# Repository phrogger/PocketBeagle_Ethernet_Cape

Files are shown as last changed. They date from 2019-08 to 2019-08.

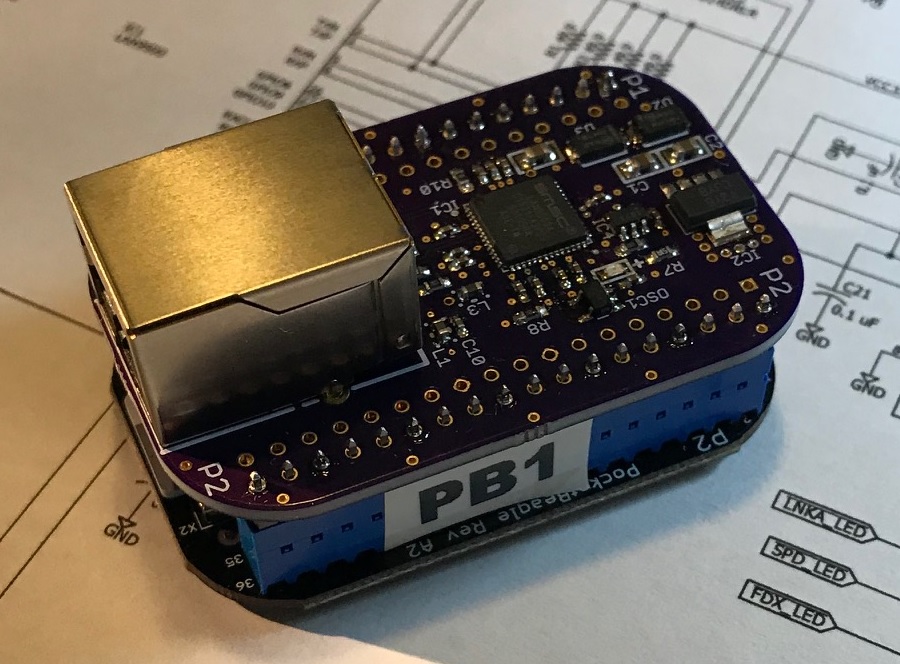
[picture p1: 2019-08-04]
PB_LAN9500A.jpg

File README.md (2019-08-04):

# PocketBeagle_Ethernet_Cape
Design Files for an Ethernet Cape for the PocketBeagle.

This design and documentation are released under the TAPR Open Hardware License.
https://www.tapr.org/ohl.html
There is no warranty as to suitability or applicability for any purpose.
There may be additional licenses or restrictions associated with the use of the Microchip LAN9500A device.

## Notes:
Board Files are Eagle 7.7

The PocketBeagle is configured so that USB Port 0 is a "slave port" only, and is the port pinned out to the Micro-USB connector on the PocketBeagle.

USB Port 1 is configured as a Master, only. It is pinned out to the I/O Expansion Connector P1, pins 3, 5, 7, 9, 11, 13, and 15. This is the port used by this Ethernet 'Cape'.

This design uses a QFN package and surface mount parts as small as 0402, in order to fit the Ethernet interface in a space as small as the PocketBeagle footprint. It is not an appropriate project for someone not experienced in SMT assembly.

The PocketBeagle has a totally symmetrical IO connector configuration. There is nothing that prevents the reversed or offset insertion of this cape. Components may be damaged if the cape is installed backwards, or offset.

This design includes an EEPROM for the permanent assignment of a MAC address to the Ethernet interface. There are software tools for the programming of this EEPROM device in the LAN9500A section of the Microchip website.
Obtaining a legitimate MAC address for use in any assembled boards is the responsibility of the builder.

Bare PC boards built from this Eagle ".brd" file are available from OshPark, minimum order of three boards:
https://oshpark.com/shared_projects/GOEnFXdS

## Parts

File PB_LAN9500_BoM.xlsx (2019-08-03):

PB_LAN9500 BoM
Partlist
Exported from PB_LAN9500.sch at 11/11/2017 3:51 PM
Part | Value | Device | Package | Library | Sheet | Manu | Manu Part No | Supplier | Supplier Part No | Notes
C01 | 1u | C-USC0805 | C0805 | 0G_RCL | 3 | KEMET | C0805C105K4RACTU | Mouser | 80-C0805C105K4R | 16 V X7R
C02 | 1u | C-USC0805 | C0805 | 0G_RCL | 3
C22 | 1u | C-USC0805 | C0805 | 0G_RCL | 2
C03 | 0.1uF | C-USC0402 | C0402 | 0G_RCL | 2 | KEMET | C0402C104K9RACTU | Mouser | 80-C0402C104K9R | 6.3V X7R
C04 | 0.1uF | C-USC0402 | C0402 | 0G_RCL | 2
C05 | 0.1uF | C-USC0402 | C0402 | 0G_RCL | 2
C06 | 0.1uF | C-USC0402 | C0402 | 0G_RCL | 2
C07 | 0.1uF | C-USC0402 | C0402 | 0G_RCL | 2
C08 | 0.1uF | C-USC0402 | C0402 | 0G_RCL | 2
C09 | 0.1uF | C-USC0402 | C0402 | 0G_RCL | 2
C10 | 0.1uF | C-USC0402 | C0402 | 0G_RCL | 2
C11 | 0.1uF | C-USC0402 | C0402 | 0G_RCL | 2
C12 | 0.1uF | C-USC0402 | C0402 | 0G_RCL | 2
C14 | 0.1uF | C-USC0402 | C0402 | 0G_RCL | 2
C15 | 0.1uF | C-USC0402 | C0402 | 0G_RCL | 2
C16 | 0.1uF | C-USC0402 | C0402 | 0G_RCL | 2
C17 | 0.1uF | C-USC0402 | C0402 | 0G_RCL | 2
C18 | 0.1uF | C-USC0402 | C0402 | 0G_RCL | 2
C19 | 0.1uF | C-USC0402 | C0402 | 0G_RCL | 2
C20 | 0.1uF | C-USC0402 | C0402 | 0G_RCL | 2
C21 | 0.1uF | C-USC0402 | C0402 | 0G_RCL | 2
D1 | LEDSMT0603 | LEDSMT0603 | LED0603 | 0G_LED_TVS | 2 | Lite-On
D2 | MBRAF1540 | MBRAF1540 | SMA-FL | 0G_Diode | 3 | ON | MBRAF1540T3G | Mouser | 863-MBRAF1540T3G
D3 | MBRAF1540 | MBRAF1540 | SMA-FL | 0G_Diode | 3 | ON | MBRAF1540T3G | Mouser | 863-MBRAF1540T3G
IC1 | LAN9500 | LAN9500 | QFN56 | 0G_Ethernet | 2 | MicroChip | LAN9500A-ABZJ | Mouser | 886-LAN9500A-ABZJ-TR
IC2 | LP38693 | LP38693 | SOT-223-4 | 0G_Regulators | 3 | TI | LP38693MP-3.3/NOPB | Mouser | 926-38693MP-3.3/NOPB
 |  |  |  |  |  | TI | LP38693MP-3.3/NOPB | Digikey | LP38693MP-3.3/NOPBCT-ND
IC3 | TPD4E0014DRLR | TPD4E0014DRLR | SOT-553-6 | 0G_Ethernet | 2 | TI | TPD4E001DRLR | Mouser | 595-TPD4E001DRLR
IC4 | 93AA66AT-I/OT | 93AA66AT-I/OT | SOT23-6 | 0G_Ethernet | 2 | MicroChip | 93AA66AT-I/OT | Mouser | 579-93AA66AT-I/OT
J1 | J0011D01BNL | J0011D01BNL | J0011D01BNL | 0G_Ethernet | 2 | Pulse | J0011D01BNL | Mouser | 673-J0011D01BNL
L1 | 220 | L0603AS | L0603AS | 0G_Ethernet | 2 | Murata | BLM18KG221SN1D | Mouser | 81-BLM18KG221SN1D | 220 Ohm 2.2A
L2 | 220 | L0603AS | L0603AS | 0G_Ethernet | 2
L3 | 220 | L0603AS | L0603AS | 0G_Ethernet | 2
OSC1 | 25 MHz | SIT2024B | SOT23-5 | 0G_Oscillators | 2 | SiTime | SIT2024BA-S2-33E-25.000000G | Digikey | 1473-1598-1-ND
PB1 | POCKETBEAGLE_OUTLINE | POCKETBEAGLE_OUTLINE | PB_OUTLINE | 0G_PockletBeagle | 3
R01 | 49.9 | R-US_R0603 | R0603 | 0G_Passives | 2 | Yageo | RC0603FR-0749R9L | Digikey | 311-49.9HRCT-ND
R02 | 49.9 | R-US_R0603 | R0603 | 0G_Passives | 2 | Yageo | RC0603FR-0749R9L | Digikey | 311-49.9HRCT-ND
R03 | 49.9 | R-US_R0603 | R0603 | 0G_Passives | 2 | Yageo | RC0603FR-0749R9L | Digikey | 311-49.9HRCT-ND
R04 | 49.9 | R-US_R0603 | R0603 | 0G_Passives | 2 | Yageo | RC0603FR-0749R9L | Digikey | 311-49.9HRCT-ND
R05 | 332 | R-US_R0603 | R0603 | 0G_Passives | 2 | Yageo | RC0603FR-07332RL | Digikey | 311-332HRCT-ND
R06 | 332 | R-US_R0603 | R0603 | 0G_Passives | 2 | Yageo | RC0603FR-07332RL | Digikey | 311-332HRCT-ND
R07 | 332 | R-US_R0603 | R0603 | 0G_Passives | 2 | Yageo | RC0603FR-07332RL | Digikey | 311-332HRCT-ND
R08 | 12.0k | R-US_R0603 | R0603 | 0G_Passives | 2 | Vishay | CRCW060312K0FKEA | Mouser | 71-CRCW0603-12K-E3
R09 | 12.0k | R-US_R0603 | R0603 | 0G_Passives | 2 | Vishay | CRCW060312K0FKEA | Mouser | 71-CRCW0603-12K-E3
R10 | 0 | R-US_R0603 | R0603 | 0G_Passives | 3 | Yageo | RC0603JR-070RL | Mouser | 603-RC0603JR-070RL
R11 | 10k | R-US_R0603 | R0603 | 0G_Passives | 2 |  |  | Mouser |  | Any R0603 10K or substitute 12.0k (R08)

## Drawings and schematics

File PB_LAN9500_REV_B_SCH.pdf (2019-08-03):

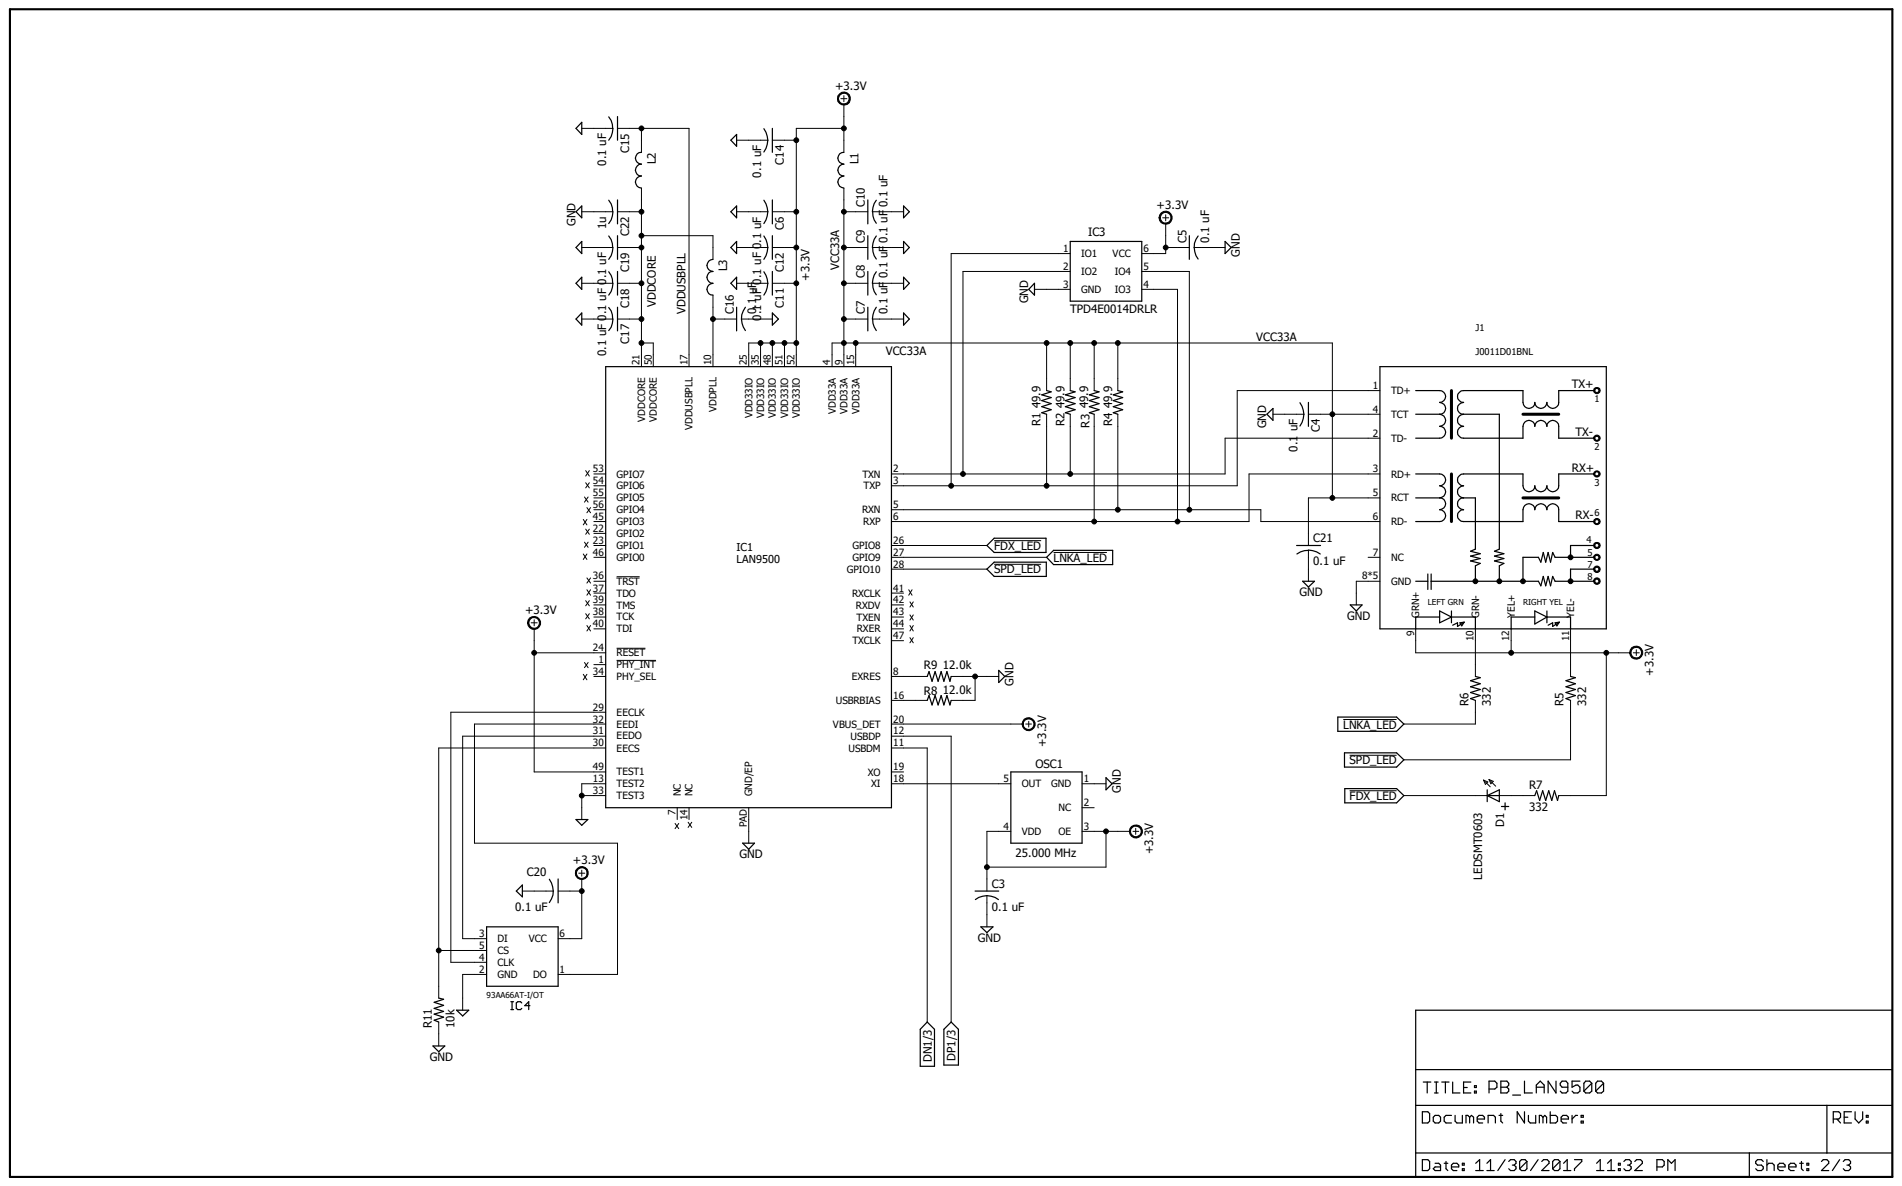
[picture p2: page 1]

9 VDD33A 15 TEST1 49 TEST2 13 VDD33IO 48 PHY_SEL 34 TRST 36 RXCLK 41 RXDV 42 TXEN 43 RXER 44 TXCLK 47

7 GPIO10 28 GPIO9 27 GPIO8 26 GPIO7 53 GPIO6 54 GPIO5 55 GPIO4 56 GPIO3 45 GPIO2 22 GPIO1 23 GPIO0 46 RESET 24 EECLK 29 EEDI 32 EEDO 31 EECS 30 TEST3 33 TDO 37 TMS 39 TCK 38 TDI 40 NC 14 GND/EP PAD

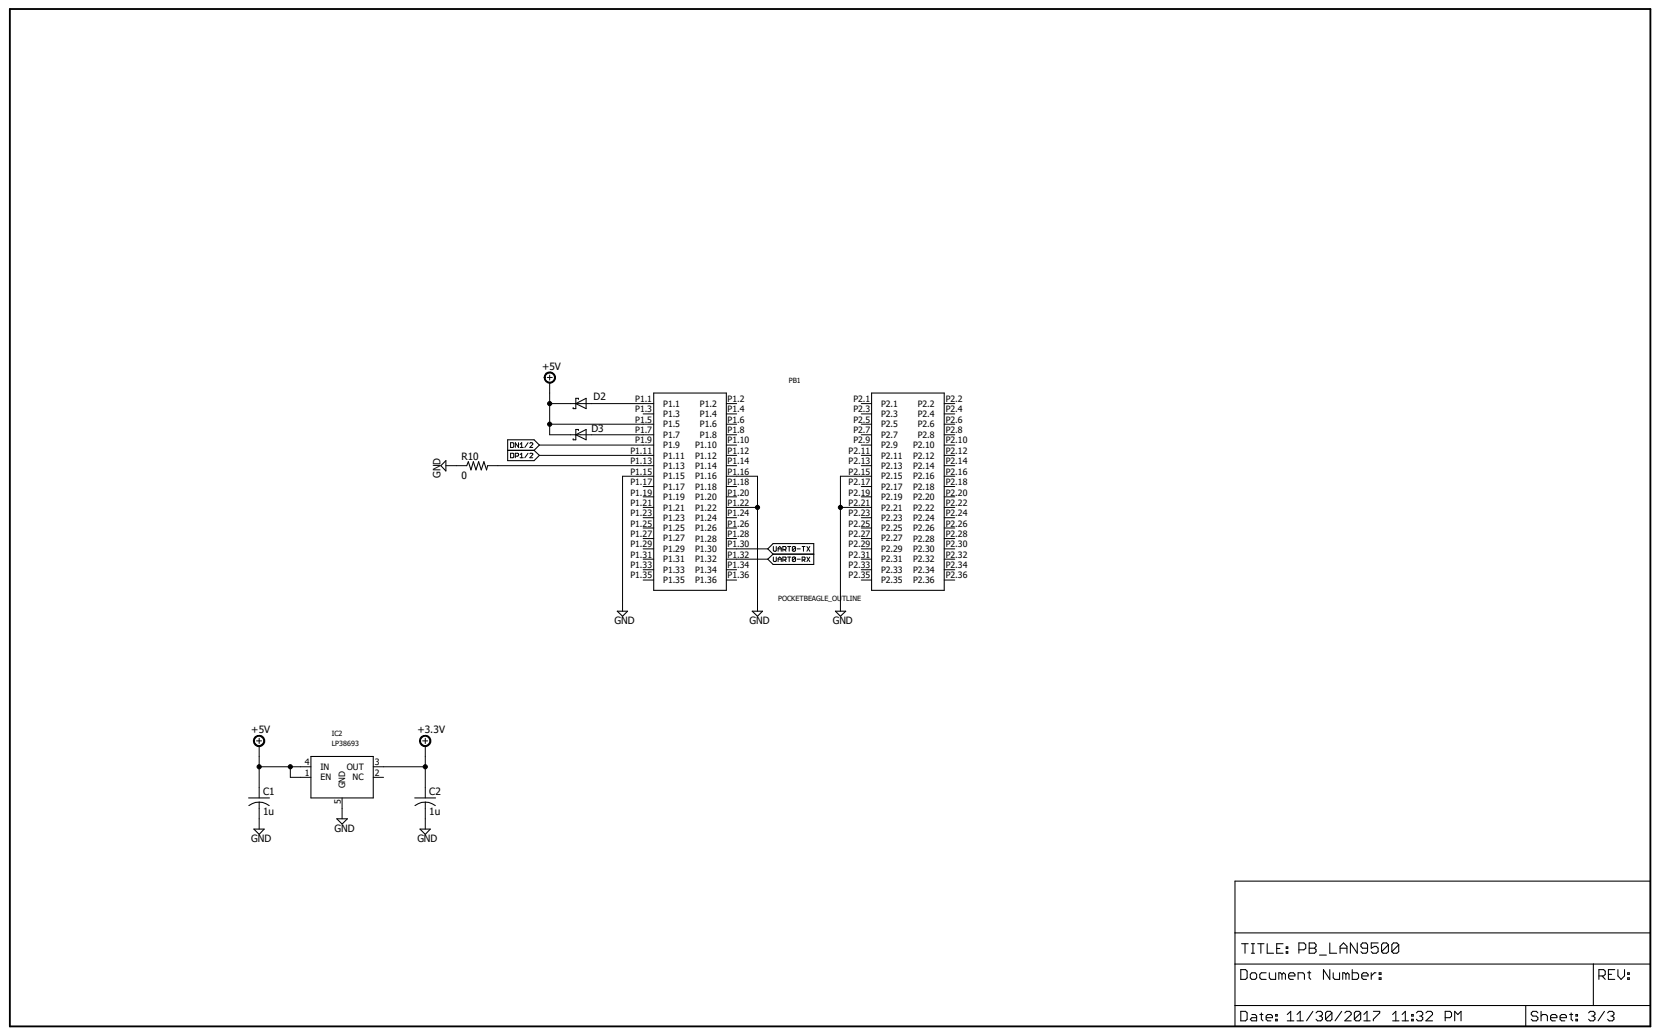
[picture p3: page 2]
POCKETBEAGLE_OUTLINE; 1u GND; GND; GND +5V GND; 5 NC 2 OUT 3 C1 C2

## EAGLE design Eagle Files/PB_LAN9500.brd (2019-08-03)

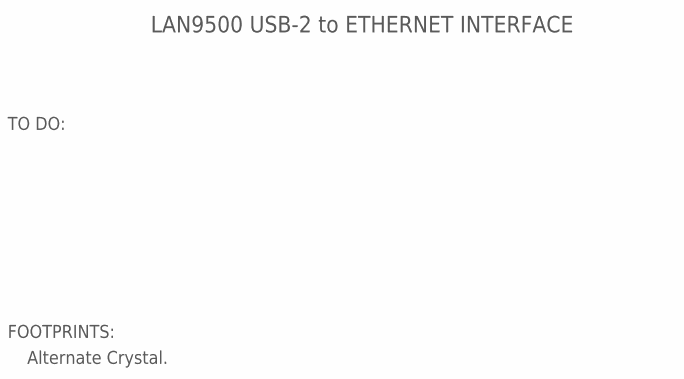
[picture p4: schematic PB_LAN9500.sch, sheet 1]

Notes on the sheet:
LAN9500 USB-2 to ETHERNET INTERFACE
TO DO:
FOOTPRINTS:
Alternate Crystal.

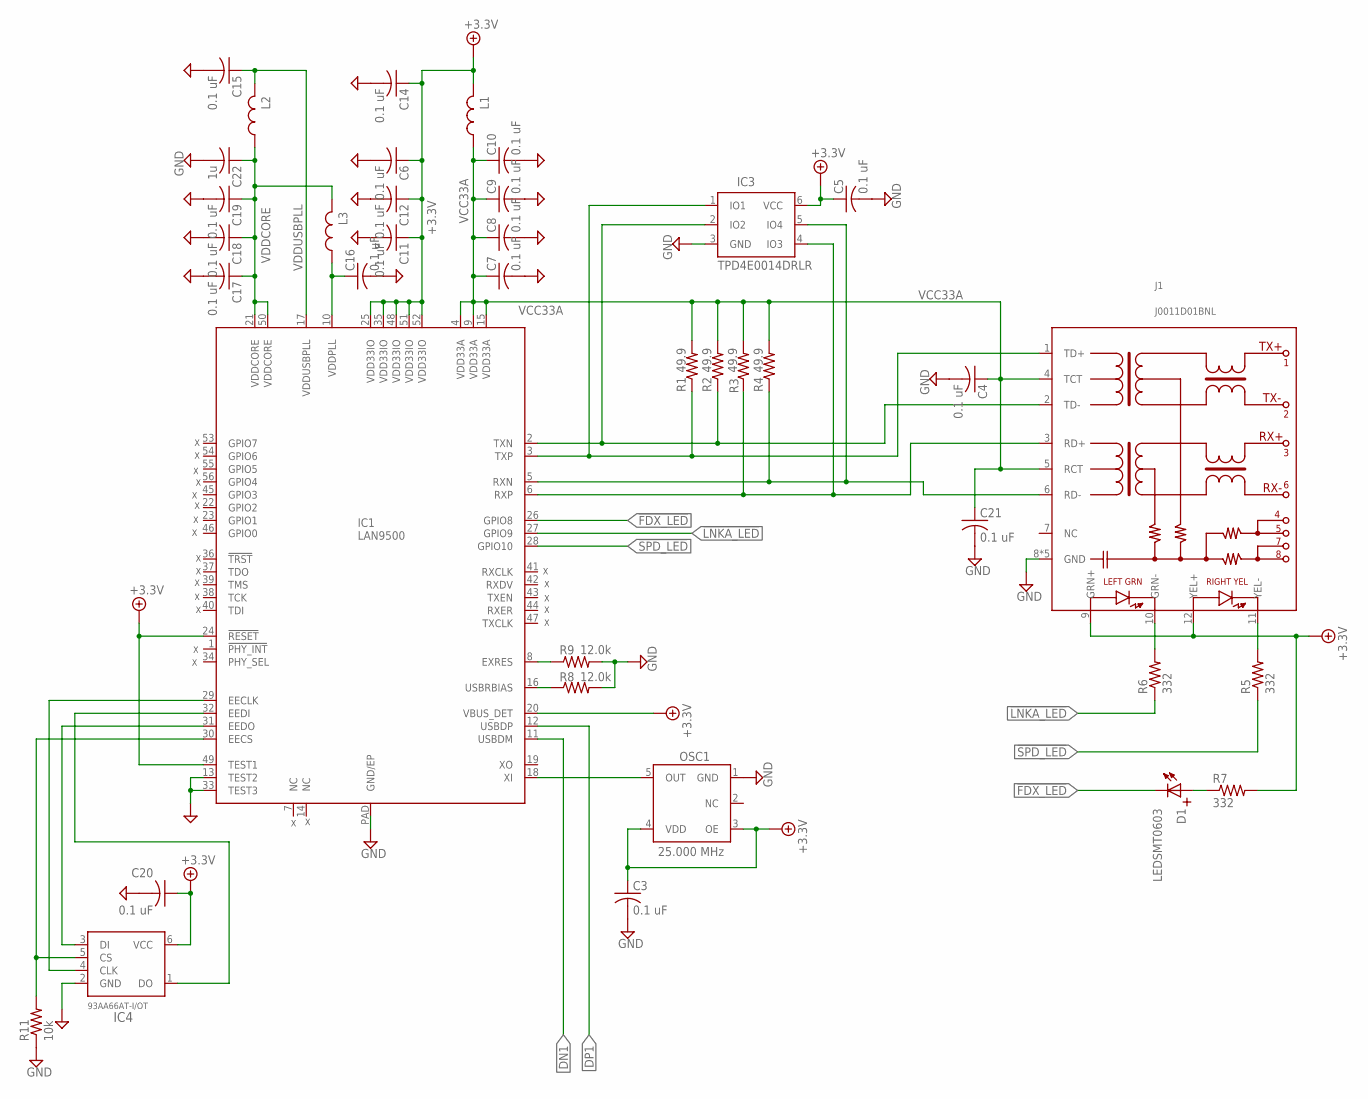
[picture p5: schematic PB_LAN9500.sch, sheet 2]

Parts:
C3, C4, C5, C6, C7, C8, C9, C10, C11, C12, C14, C15, C16, C17, C18, C19, C20, C21: 0.1 uF; C0402
C22: 1u; C0805
D1: LEDSMT0603; LED0603
IC1: LAN9500; QFN56
IC3: TPD4E0014DRLR; SOT-553-6
IC4: 93AA66AT-I/OT; SOT23-6
J1: J0011D01BNL
L1, L2, L3: L0603AS
OSC1: 25.000 MHz; SOT23-5
R1, R2, R3, R4: 49.9; R0603
R5, R6, R7: 332; R0603
R8, R9: 12.0k; R0603
R11: 10k; R0603

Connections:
!FDX_LED: D1.P$2 (K), IC1.26 (GPIO8)
!LNKA_LED: IC1.27 (GPIO9), R6.1
!SPD_LED: IC1.28 (GPIO10), R5.1
+3.3V: C3.1, C5.1, C6.1, C11.1, C12.1, C14.1, C20.1, IC1.20 (VBUS_DET), IC1.24 (!RESET), IC1.25 (VDD33IO), IC1.35 (VDD33IO), IC1.48 (VDD33IO), IC1.49 (TEST1), IC1.51 (VDD33IO), IC1.52 (VDD33IO), IC3.6 (VCC), IC4.6 (VCC), J1.9 (GRN+), J1.12 (YEL+), L1.2, OSC1.3 (OE), OSC1.4 (VDD), R7.2; also elsewhere on the board
DN1: IC1.11 (USBDM); also elsewhere on the board
DP1: IC1.12 (USBDP); also elsewhere on the board
GND: C3.2, C4.2, C5.2, C6.2, C7.2, C8.2, C9.2, C10.2, C11.2, C12.2, C14.2, C15.2, C16.2, C17.2, C18.2, C19.2, C20.2, C21.2, C22.2, IC1.13 (TEST2), IC1.33 (TEST3), IC1.PAD (GND/EP), IC3.3 (GND), IC4.2 (GND), J1.8 (GND), J1.GND1 (GND), J1.GND2 (GND), J1.GND3 (GND), J1.GND4 (GND), OSC1.1 (GND), R8.2, R9.2, R11.1; also elsewhere on the board
unnamed: J1.11 (YEL-), R5.2
unnamed: IC1.30 (EECS), IC4.5 (CS), R11.2
unnamed: IC1.29 (EECLK), IC4.4 (CLK)
unnamed: IC1.31 (EEDO), IC4.3 (DI)
unnamed: IC1.32 (EEDI), IC4.1 (DO)
unnamed: IC1.8 (EXRES), R9.1
unnamed: IC1.16 (USBRBIAS), R8.1
unnamed: D1.P$1 (A), R7.1
unnamed: J1.10 (GRN-), R6.2
unnamed: IC1.18 (XI), OSC1.5 (OUT)
RXN: IC1.5 (RXN), IC3.5 (IO4), J1.6 (RD-), R4.1
RXP: IC1.6 (RXP), IC3.4 (IO3), J1.3 (RD+), R3.1
TXN: IC1.2 (TXN), IC3.2 (IO2), J1.2 (TD-), R2.1
TXP: IC1.3 (TXP), IC3.1 (IO1), J1.1 (TD+), R1.1
VCC33A: C4.1, C7.1, C8.1, C9.1, C10.1, C21.1, IC1.4 (VDD33A), IC1.9 (VDD33A), IC1.15 (VDD33A), J1.4 (TCT), J1.5 (RCT), L1.1, R1.2, R2.2, R3.2, R4.2
VDDCORE: C17.1, C18.1, C19.1, C22.1, IC1.21 (VDDCORE), IC1.50 (VDDCORE), L2.1, L3.2
VDDPLL: C16.1, IC1.10 (VDDPLL), L3.1
VDDUSBPLL: C15.1, IC1.17 (VDDUSBPLL), L2.2

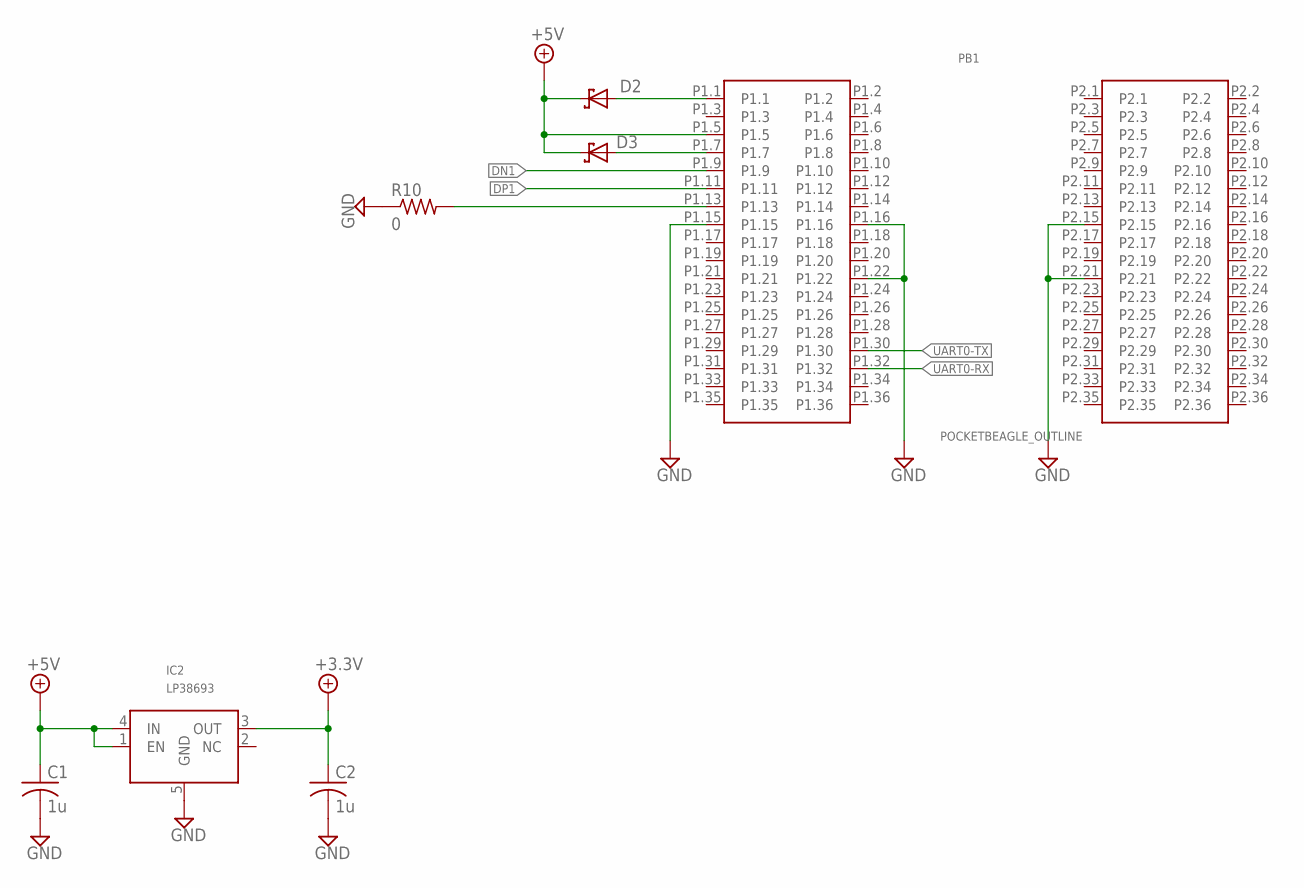
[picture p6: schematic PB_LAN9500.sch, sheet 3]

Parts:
C1, C2: 1u; C0805
D2, D3: MBRAF1540; SMA-FL
IC2: LP38693; SOT-223-4
PB1: POCKETBEAGLE_OUTLINE; PB_OUTLINE
R10: 0; R0603

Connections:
+3.3V: C2.1, IC2.3 (OUT); also elsewhere on the board
+5V: C1.1, D2.C, D3.C, IC2.1 (EN), IC2.4 (IN), PB1.P1.5
DN1: PB1.P1.9; also elsewhere on the board
DP1: PB1.P1.11; also elsewhere on the board
GND: C1.2, C2.2, IC2.5 (GND), PB1.P1.15, PB1.P1.16, PB1.P1.22, PB1.P2.15, PB1.P2.21, R10.1; also elsewhere on the board
ID1: PB1.P1.13, R10.2
unnamed: D3.A, PB1.P1.7
unnamed: D2.A, PB1.P1.1
UART0-RX: PB1.P1.32
UART0-TX: PB1.P1.30

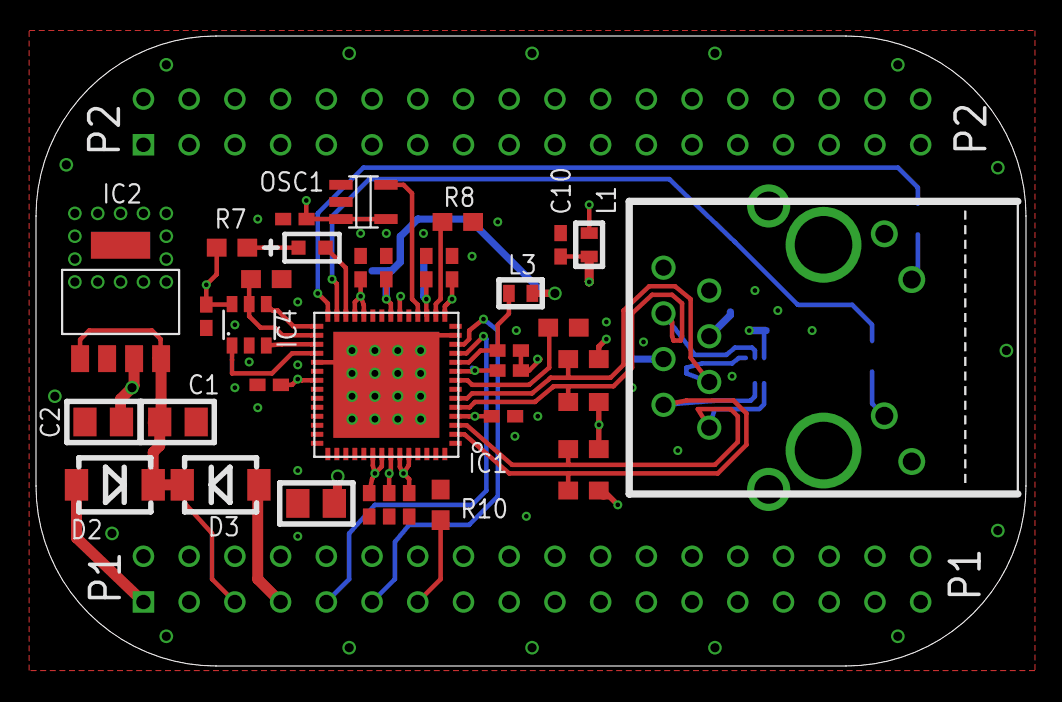
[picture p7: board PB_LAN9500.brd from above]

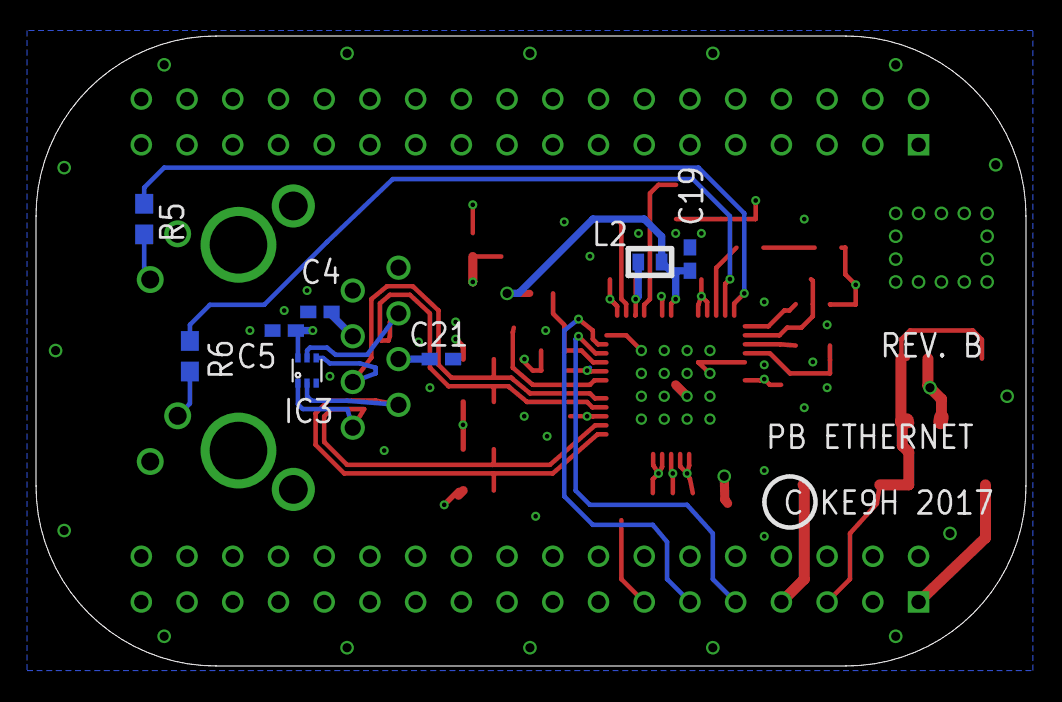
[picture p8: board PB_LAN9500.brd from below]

Board: 4 copper layers, 55.0 x 35.0 mm, 45 parts (8 on the bottom side), 29 nets.

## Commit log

2019-08-03 Initial Commit of Eagle Design Files
    [PB_LAN9500.brd, PB_LAN9500.sch, PB_LAN9500_BoM.xlsx]
2019-08-04 Added ".jpg" of assembled unit.
